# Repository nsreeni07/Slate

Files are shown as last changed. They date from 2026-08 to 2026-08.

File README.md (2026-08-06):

# Slate
A custom mechanical keyboard designed from scratch in CAD, it has a 65%-style layout with hot-swappable key switches, a Raspberry Pi Pico as the controller, screw-in stabilizers. I built this keyboard because for a long time I have always wanted my own keyboard and the keyboard on my laptop isnt the best. I also made a custom wrist rest to make typing easier for long durations. 

Onshape Link(Assembly is in here): https://cad.onshape.com/documents/2fce0d74e6bb764dbe1d5886/w/852f830710264ff3d6b37b5a/e/681bf4a4fe9575b6e24b9726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






Part,Quantity,Total Price,Link
Cas,1,$0,Printing-Legion
PCB,1,$39,JLCPCB
Key Switches,90,$36.76,https://www.aliexpress.us/item/3256809309954256.html
Raspberry Pi Pico,1,$3.70,https://www.aliexpress.us/item/3256809657712980.html
Screw-in Stabilizers,1,$6.00,https://www.aliexpress.us/item/3256807050530252.html
Keycaps,114,$19.27,https://www.aliexpress.us/item/3256808312477768.html
Diodes,100,$2.50,https://www.aliexpress.us/item/3256811580628264.html

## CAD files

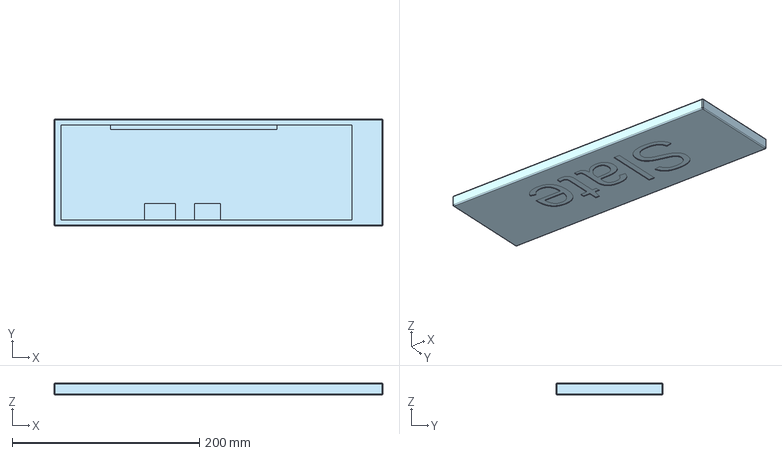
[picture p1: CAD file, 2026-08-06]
Cad/Keyboard Case.step
351.8 x 114.3 x 12.7 mm

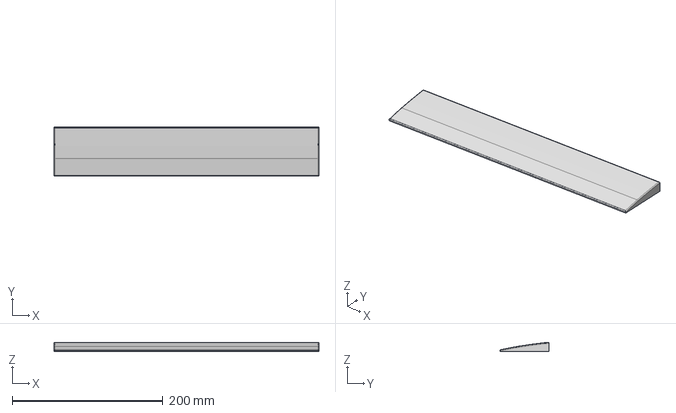
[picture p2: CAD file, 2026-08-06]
Cad/Handrest.step
351.8 x 65.1 x 12.5 mm

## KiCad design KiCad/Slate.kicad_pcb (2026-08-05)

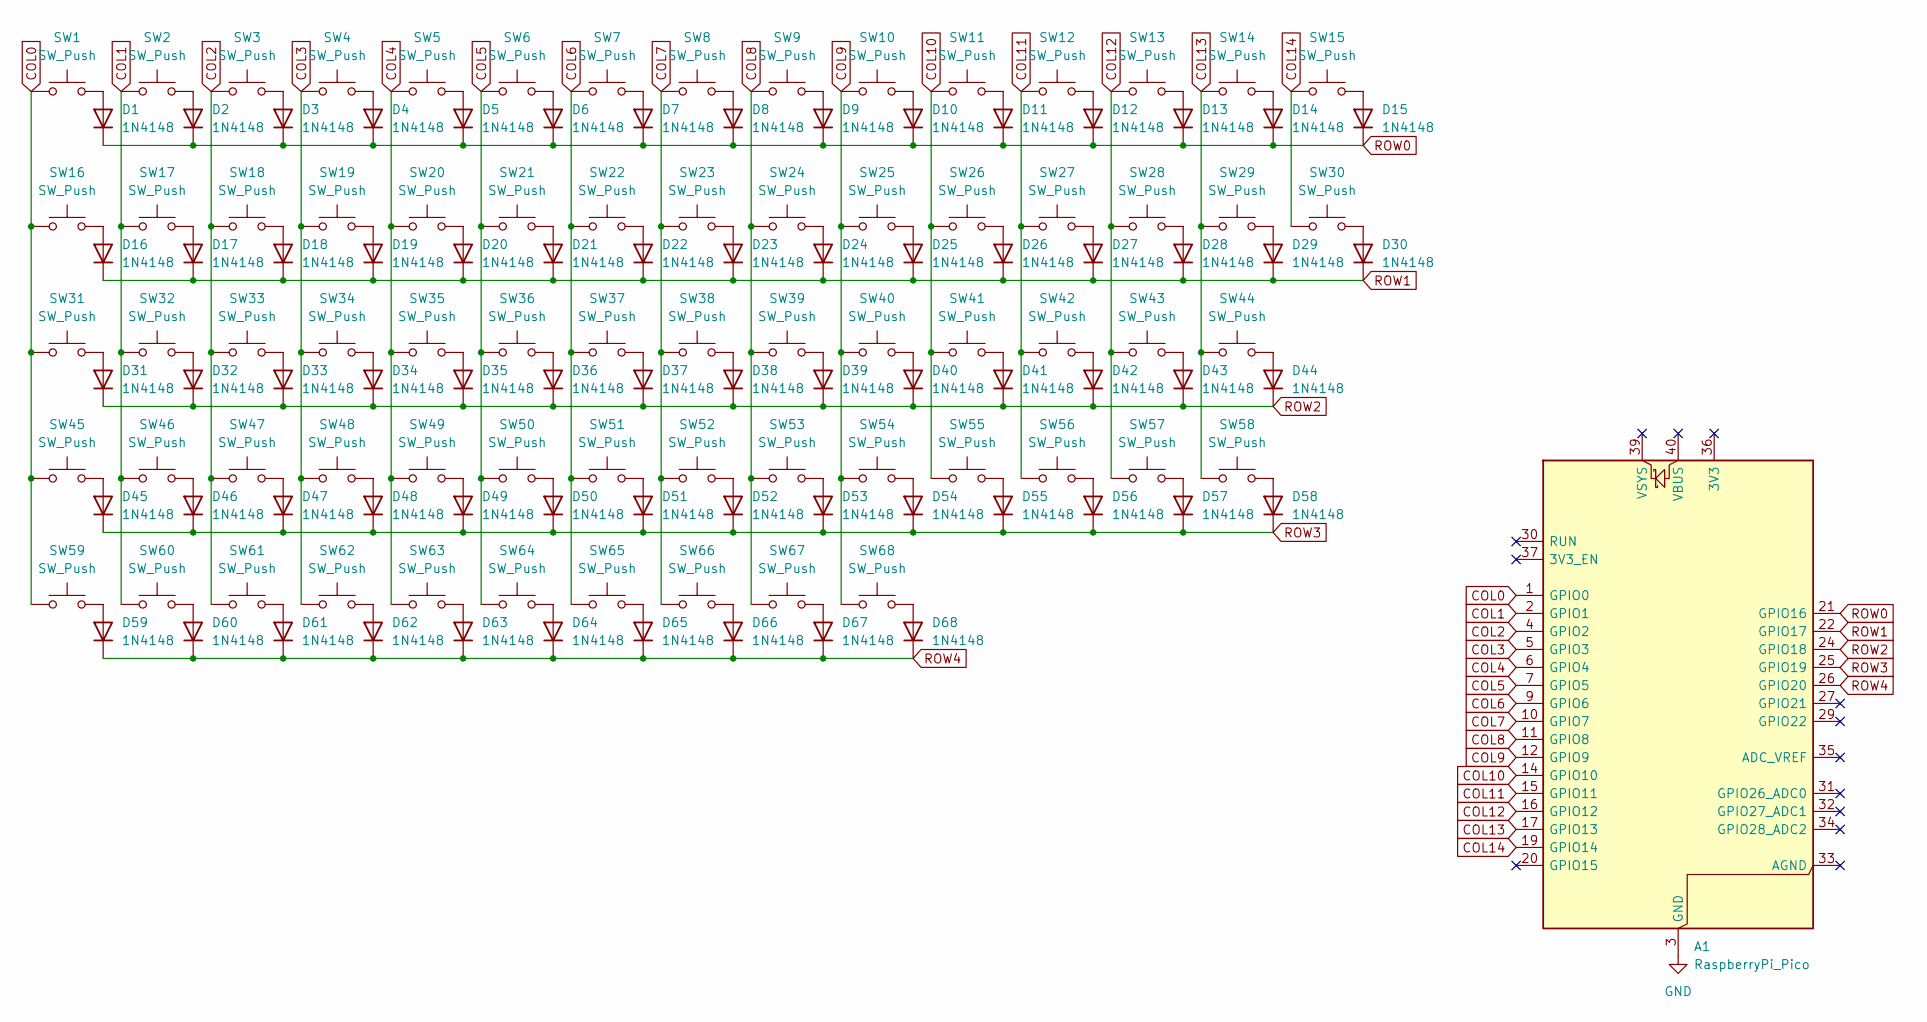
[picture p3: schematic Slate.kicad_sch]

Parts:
A1: RaspberryPi_Pico; RaspberryPi_Pico_Common_Unspecified
D1, D2, D3, D4, D5, D6, D7, D8, D9, D10, D11, D12, D13, D14, D15, D16, D17, D18, D19, D20, D21, D22, D23, D24, D25, D26, D27, D28, D29, D30, D31, D32, D33, D34, D35, D36, D37, D38, D39, D40, D41, D42, D43, D44, D45, D46, D47, D48, D49, D50, D51, D52, D53, D54, D55, D56, D57, D58, D59, D60, D61, D62, D63, D64, D65, D66, D67, D68: 1N4148; D_DO-35_SOD27_P7.62mm_Horizontal
SW1, SW2, SW3, SW4, SW5, SW6, SW7, SW8, SW9, SW10, SW11, SW12, SW13, SW15, SW17, SW18, SW19, SW20, SW21, SW22, SW23, SW24, SW25, SW26, SW27, SW28, SW30, SW32, SW33, SW34, SW35, SW36, SW37, SW38, SW39, SW40, SW41, SW42, SW44, SW46, SW47, SW48, SW49, SW50, SW51, SW52, SW53, SW54, SW55, SW57, SW58, SW63, SW64, SW65, SW66, SW67, SW68: SW_Push; SW_Cherry_MX_1.00u_PCB
SW14: SW_Push; SW_Cherry_MX_2.00u_PCB
SW16, SW29: SW_Push; SW_Cherry_MX_1.50u_PCB
SW31, SW56: SW_Push; SW_Cherry_MX_1.75u_PCB
SW43, SW45: SW_Push; SW_Cherry_MX_2.25u_PCB
SW59, SW60, SW61: SW_Push; SW_Cherry_MX_1.25u_PCB
SW62: SW_Push; SW_Cherry_MX_6.25u_PCB

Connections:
COL0: A1.1 (GPIO0), SW1.1, SW16.1, SW31.1, SW45.1, SW59.1
COL1: A1.2 (GPIO1), SW2.1, SW17.1, SW32.1, SW46.1, SW60.1
COL2: A1.4 (GPIO2), SW3.1, SW18.1, SW33.1, SW47.1, SW61.1
COL3: A1.5 (GPIO3), SW4.1, SW19.1, SW34.1, SW48.1, SW62.1
COL4: A1.6 (GPIO4), SW5.1, SW20.1, SW35.1, SW49.1, SW63.1
COL5: A1.7 (GPIO5), SW6.1, SW21.1, SW36.1, SW50.1, SW64.1
COL6: A1.9 (GPIO6), SW7.1, SW22.1, SW37.1, SW51.1, SW65.1
COL7: A1.10 (GPIO7), SW8.1, SW23.1, SW38.1, SW52.1, SW66.1
COL8: A1.11 (GPIO8), SW9.1, SW24.1, SW39.1, SW53.1, SW67.1
COL9: A1.12 (GPIO9), SW10.1, SW25.1, SW40.1, SW54.1, SW68.1
COL10: A1.14 (GPIO10), SW11.1, SW26.1, SW41.1, SW55.1
COL11: A1.15 (GPIO11), SW12.1, SW27.1, SW42.1, SW56.1
COL12: A1.16 (GPIO12), SW13.1, SW28.1, SW43.1, SW57.1
COL13: A1.17 (GPIO13), SW14.1, SW29.1, SW44.1, SW58.1
COL14: A1.19 (GPIO14), SW15.1, SW30.1
GND: A1.3 (GND), A1.8 (GND), A1.13 (GND), A1.18 (GND), A1.23 (GND), A1.28 (GND), A1.38 (GND)
unnamed: D1.2 (A), SW1.2
unnamed: D2.2 (A), SW2.2
unnamed: D3.2 (A), SW3.2
unnamed: D4.2 (A), SW4.2
unnamed: D5.2 (A), SW5.2
unnamed: D6.2 (A), SW6.2
unnamed: D7.2 (A), SW7.2
unnamed: D8.2 (A), SW8.2
unnamed: D9.2 (A), SW9.2
unnamed: D10.2 (A), SW10.2
unnamed: D11.2 (A), SW11.2
unnamed: D12.2 (A), SW12.2
unnamed: D13.2 (A), SW13.2
unnamed: D14.2 (A), SW14.2
unnamed: D15.2 (A), SW15.2
unnamed: D16.2 (A), SW16.2
unnamed: D17.2 (A), SW17.2
unnamed: D18.2 (A), SW18.2
unnamed: D19.2 (A), SW19.2
unnamed: D20.2 (A), SW20.2
unnamed: D21.2 (A), SW21.2
unnamed: D22.2 (A), SW22.2
unnamed: D23.2 (A), SW23.2
unnamed: D24.2 (A), SW24.2
unnamed: D25.2 (A), SW25.2
unnamed: D26.2 (A), SW26.2
unnamed: D27.2 (A), SW27.2
unnamed: D28.2 (A), SW28.2
unnamed: D29.2 (A), SW29.2
unnamed: D30.2 (A), SW30.2
unnamed: D31.2 (A), SW31.2
unnamed: D32.2 (A), SW32.2
unnamed: D33.2 (A), SW33.2
unnamed: D34.2 (A), SW34.2
unnamed: D35.2 (A), SW35.2
unnamed: D36.2 (A), SW36.2
unnamed: D37.2 (A), SW37.2
unnamed: D38.2 (A), SW38.2
unnamed: D39.2 (A), SW39.2
unnamed: D40.2 (A), SW40.2
unnamed: D41.2 (A), SW41.2
unnamed: D42.2 (A), SW42.2
unnamed: D43.2 (A), SW43.2
unnamed: D44.2 (A), SW44.2
unnamed: D45.2 (A), SW45.2
unnamed: D46.2 (A), SW46.2
unnamed: D47.2 (A), SW47.2
unnamed: D48.2 (A), SW48.2
unnamed: D49.2 (A), SW49.2
unnamed: D50.2 (A), SW50.2
unnamed: D51.2 (A), SW51.2
unnamed: D52.2 (A), SW52.2
unnamed: D53.2 (A), SW53.2
unnamed: D54.2 (A), SW54.2
unnamed: D55.2 (A), SW55.2
unnamed: D56.2 (A), SW56.2
unnamed: D57.2 (A), SW57.2
unnamed: D58.2 (A), SW58.2
unnamed: D59.2 (A), SW59.2
unnamed: D60.2 (A), SW60.2
unnamed: D61.2 (A), SW61.2
unnamed: D62.2 (A), SW62.2
unnamed: D63.2 (A), SW63.2
unnamed: D64.2 (A), SW64.2
unnamed: D65.2 (A), SW65.2
unnamed: D66.2 (A), SW66.2
unnamed: D67.2 (A), SW67.2
unnamed: D68.2 (A), SW68.2
ROW0: A1.21 (GPIO16), D1.1 (K), D2.1 (K), D3.1 (K), D4.1 (K), D5.1 (K), D6.1 (K), D7.1 (K), D8.1 (K), D9.1 (K), D10.1 (K), D11.1 (K), D12.1 (K), D13.1 (K), D14.1 (K), D15.1 (K)
ROW1: A1.22 (GPIO17), D16.1 (K), D17.1 (K), D18.1 (K), D19.1 (K), D20.1 (K), D21.1 (K), D22.1 (K), D23.1 (K), D24.1 (K), D25.1 (K), D26.1 (K), D27.1 (K), D28.1 (K), D29.1 (K), D30.1 (K)
ROW2: A1.24 (GPIO18), D31.1 (K), D32.1 (K), D33.1 (K), D34.1 (K), D35.1 (K), D36.1 (K), D37.1 (K), D38.1 (K), D39.1 (K), D40.1 (K), D41.1 (K), D42.1 (K), D43.1 (K), D44.1 (K)
ROW3: A1.25 (GPIO19), D45.1 (K), D46.1 (K), D47.1 (K), D48.1 (K), D49.1 (K), D50.1 (K), D51.1 (K), D52.1 (K), D53.1 (K), D54.1 (K), D55.1 (K), D56.1 (K), D57.1 (K), D58.1 (K)
ROW4: A1.26 (GPIO20), D59.1 (K), D60.1 (K), D61.1 (K), D62.1 (K), D63.1 (K), D64.1 (K), D65.1 (K), D66.1 (K), D67.1 (K), D68.1 (K)

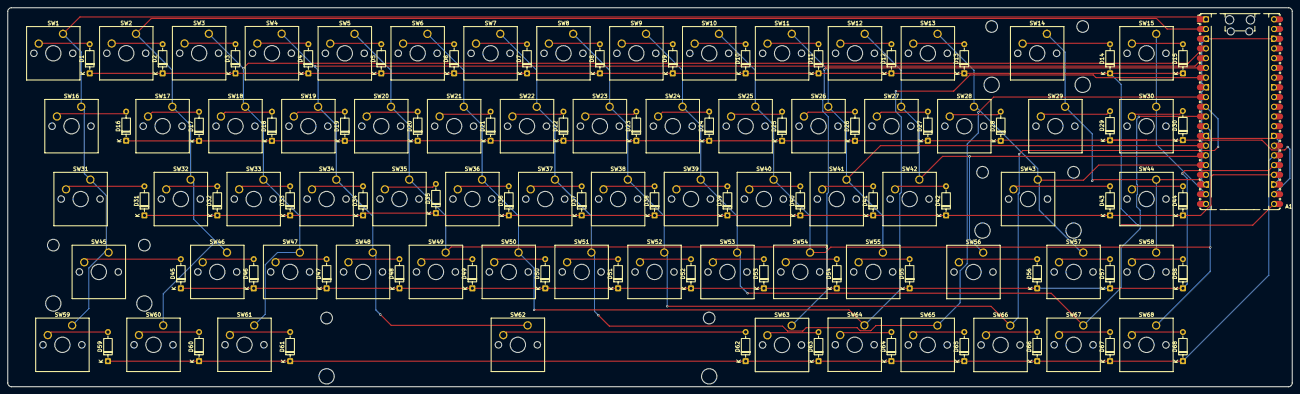
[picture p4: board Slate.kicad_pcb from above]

Board: 2 copper layers, 335.8 x 99.1 mm, 137 parts (0 on the bottom side), 89 nets.

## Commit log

2026-08-05 Add missing link for Key Switches in BOM.csv
    [BOM.csv]
2026-08-06 Rename Keyboard Case.step to Cad/Keyboard Case.step
    [Keyboard Case.step]
2026-10-05 Update total price for Cas in BOM.csv
    [BOM.csv]
2026-10-25 Modify Key Switches price and link in BOM.csv
    Updated the price and link for Key Switches in BOM.
2026-10-25 Revise JOURNAL.md with time updates and new entries
    Updated total time spent on various tasks and added entries for PCB routing and CAD design.
2026-10-25 Update Key Switches price in BOM.csv
    Updated the price of Key Switches from $22.5 to $27.00.
